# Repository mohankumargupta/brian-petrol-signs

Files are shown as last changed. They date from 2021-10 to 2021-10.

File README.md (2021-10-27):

# Big LED Matrix from Petrol Pump Signage

#### Info

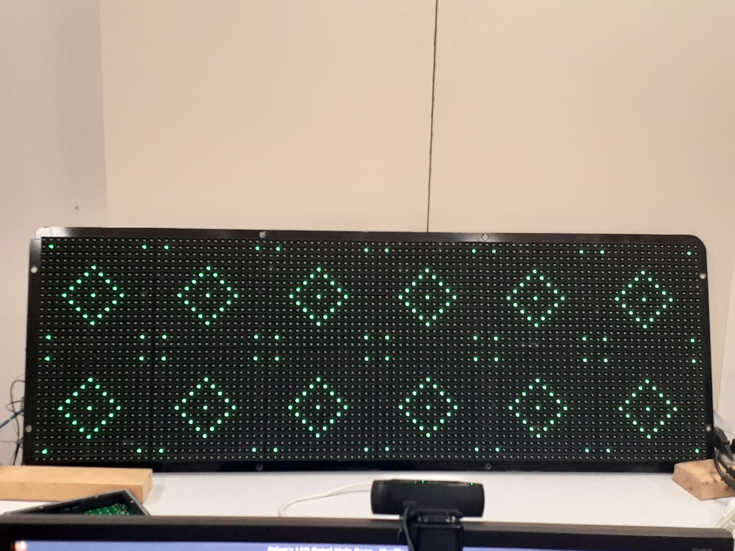
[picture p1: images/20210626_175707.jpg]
LED Panel Demo


Not the usual HUB08/HUB12/HUB40/HUB75 style setup. Inner workings [here](https://github.com/microcontrollersig/brian-led-matrix-petrol-signs/blob/main/REVERSEENGINEER.md)

They usually come in 6 panels wide, 2 panels height (effectively becomes a 96x32 single-color LED matrix)

# PCB Controller for LED matrix

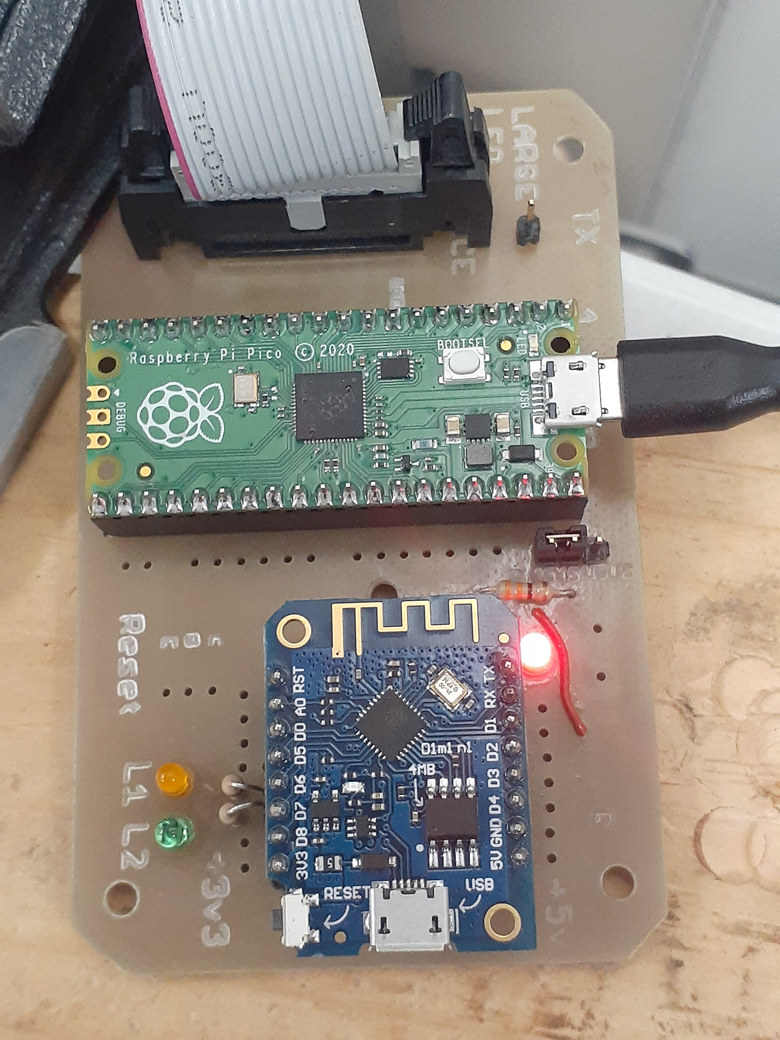
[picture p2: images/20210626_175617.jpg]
LED matrix controller


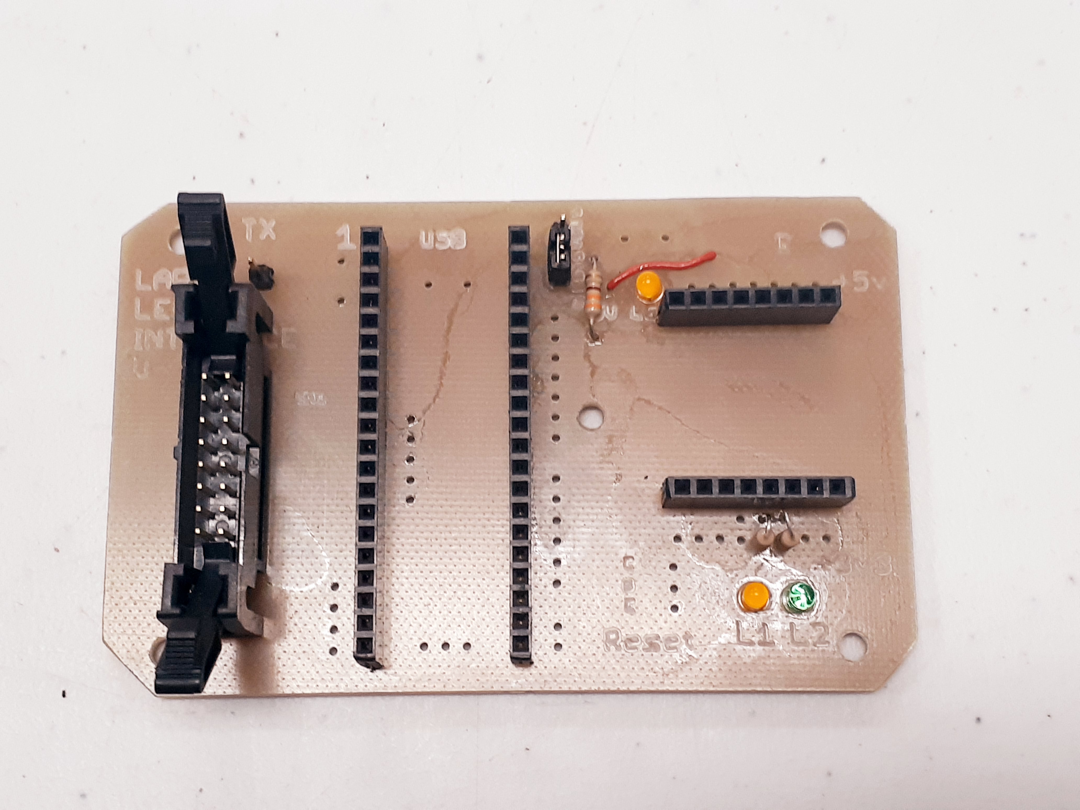
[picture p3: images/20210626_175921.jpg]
PCB controller


#### Bill of Materials

| Qty | |Code | Where to Buy | Required |
| --- |---|---| --- | --- |
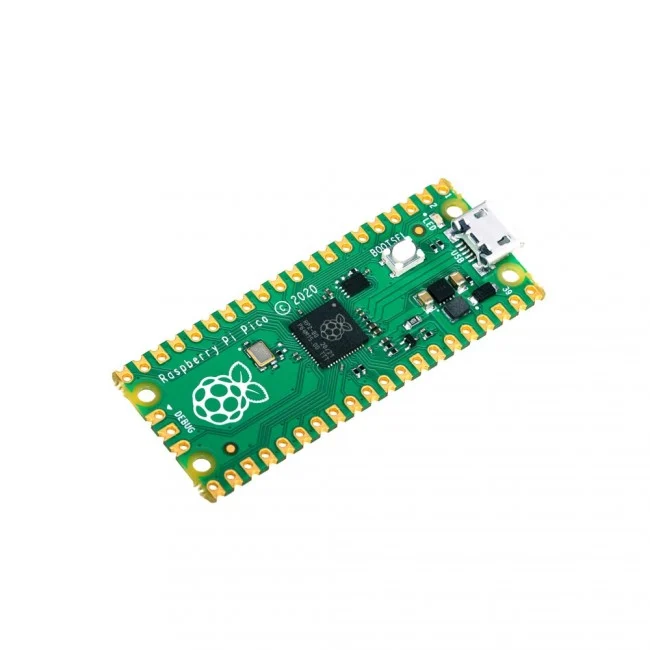
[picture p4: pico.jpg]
Pico
| 1 | |[Raspberry Pico](https://www.raspberrypi.org/documentation/rp2040/getting-started/) | [Pi Australia](https://raspberry.piaustralia.com.au/products/raspberry-pi-pico?variant=32587824070705)<br/>[Altronics](https://www.altronics.com.au/p/z6421-raspberry-pi-pico-microcontroller-board/)<br/>[Element 14](https://au.element14.com/raspberry-pi/raspberry-pi-pico/raspberry-pi-32bit-arm-cortex/dp/3643332)<br/>[Core Electronics](https://core-electronics.com.au/raspberry-pi-pico.html)| Y |
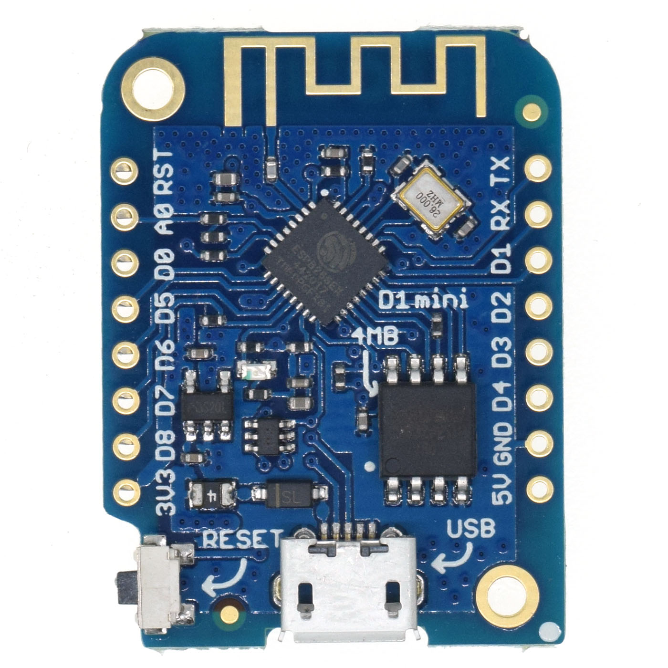
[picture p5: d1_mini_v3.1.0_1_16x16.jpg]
D1 mini
| 1 |  | [ESP8266 Wemos D1 mini](https://www.wemos.cc/en/latest/d1/d1_mini.html) | [Aliexpress - color: d1 mini](https://www.aliexpress.com/item/32651747570.html)  | Y |
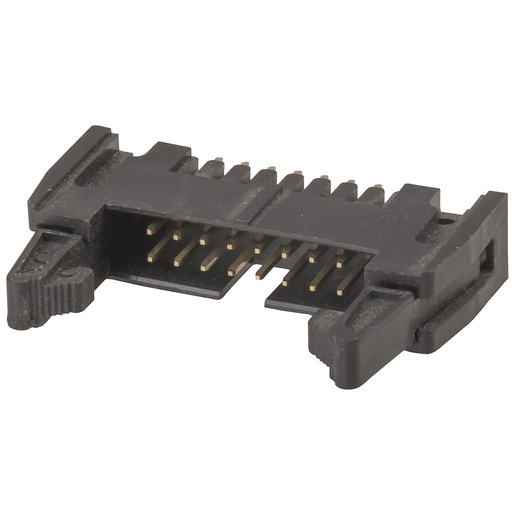
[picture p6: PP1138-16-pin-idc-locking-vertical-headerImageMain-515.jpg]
16 Pin IDC
| 1 |  | [16 Pin IDC Locking Vertical Header](https://www.jaycar.com.au/16-pin-idc-locking-vertical-header/p/PP1138) | 16-pin ribbon header| Y |
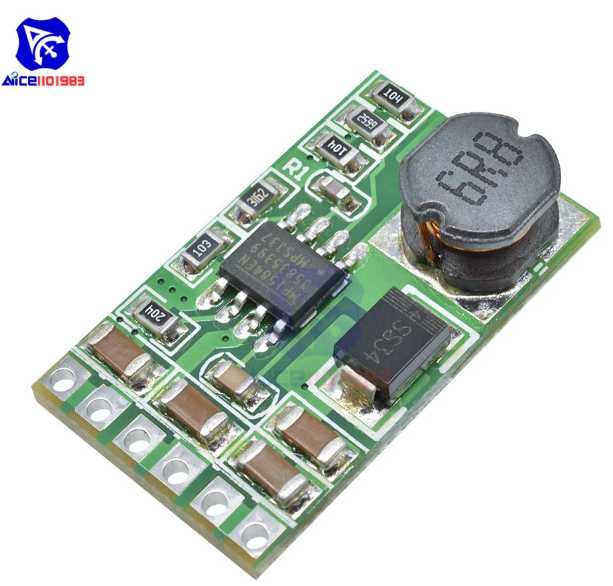
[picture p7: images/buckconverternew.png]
buck converter
| 1 |  | [3.5A buck converter - color: 5V](https://www.aliexpress.com/item/33036075561.html) | Buck converter | Y | 
| 1 | Terminal block | [Terminal block](https://www.altronics.com.au/p/p2041a-dinkle-3-way-5.08mm-pcb-mount-terminal-block/) | External power source | Y |
| 1 | Female header | [Female header](https://www.jaycar.com.au/40-pin-female-header-strip/p/HM3230) | Female header for Pico | Y |
| 1 | Right-angle connector | [Right-angle connector ](https://www.altronics.com.au/p/p5440-oupiin-40-way-90-degree-header-pin/) | Need for connecting buck converter | Y |
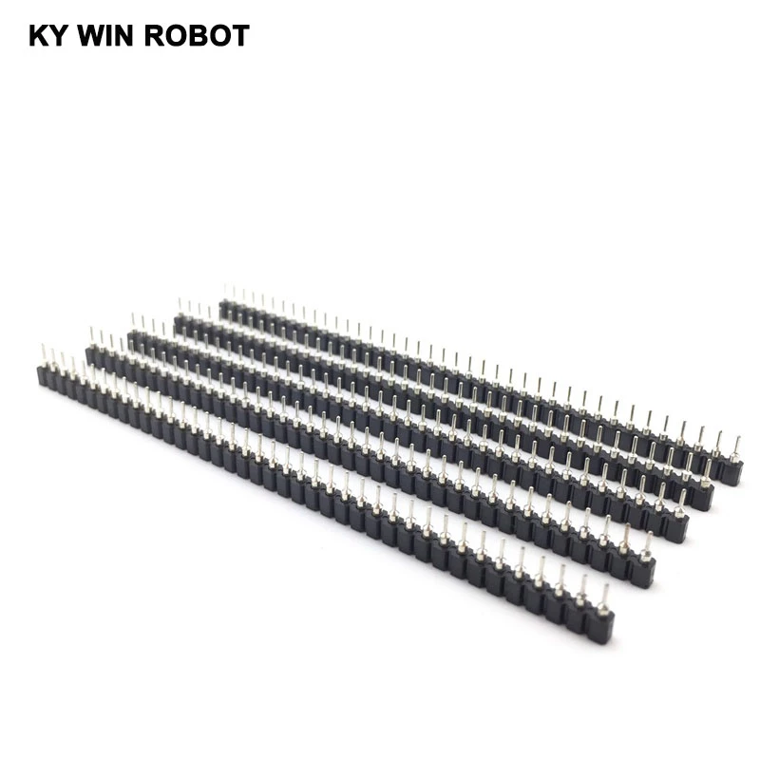
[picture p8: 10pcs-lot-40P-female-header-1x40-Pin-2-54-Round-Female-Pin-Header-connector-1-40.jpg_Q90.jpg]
Female Header
| 1 |  | [Round Female Pin Header connector - snapable](https://www.aliexpress.com/item/32848204130.html)  | Aliexpress | N |
| 1 | 2N2222A | [2N2222A NPN transistor](https://www.jaycar.com.au/2n2222a-npn-transistor/p/ZT2298) |  Pico software-controlled reset switch  | N |

#### EAGLE Schematic for PCB Board
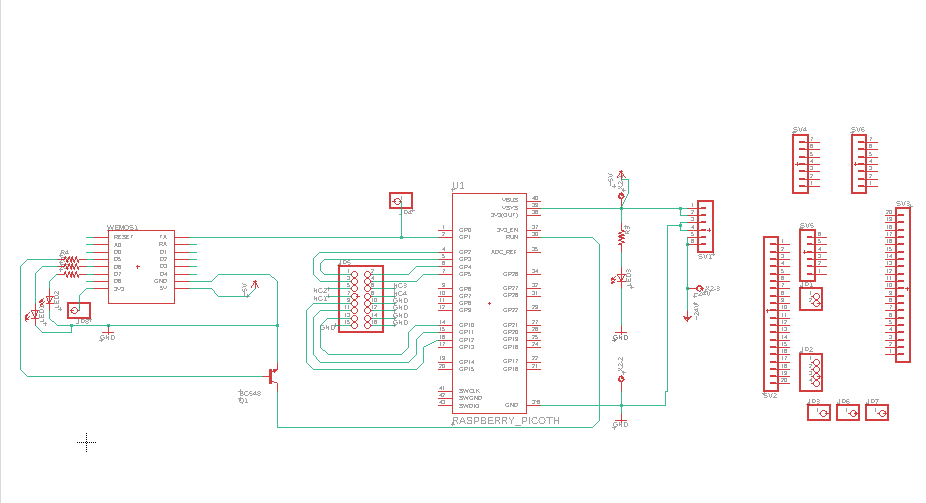
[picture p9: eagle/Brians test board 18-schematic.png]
schematic


#### EAGLE Board file for PCB Board

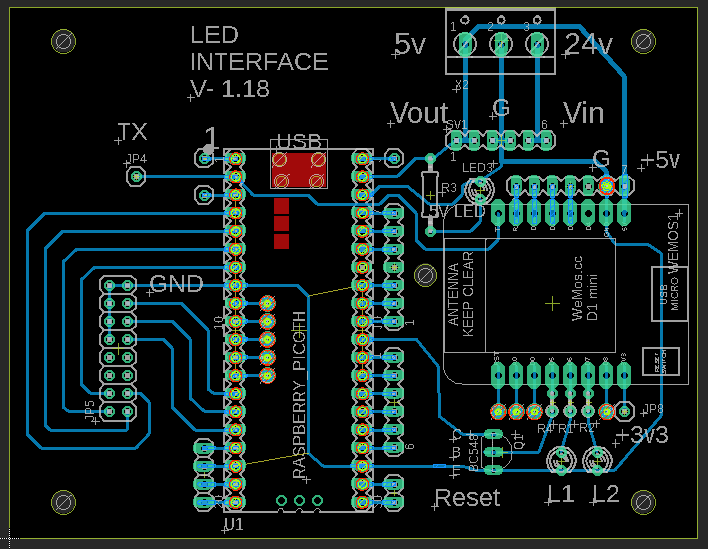
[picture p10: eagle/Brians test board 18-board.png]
board


### PCB Top Layer

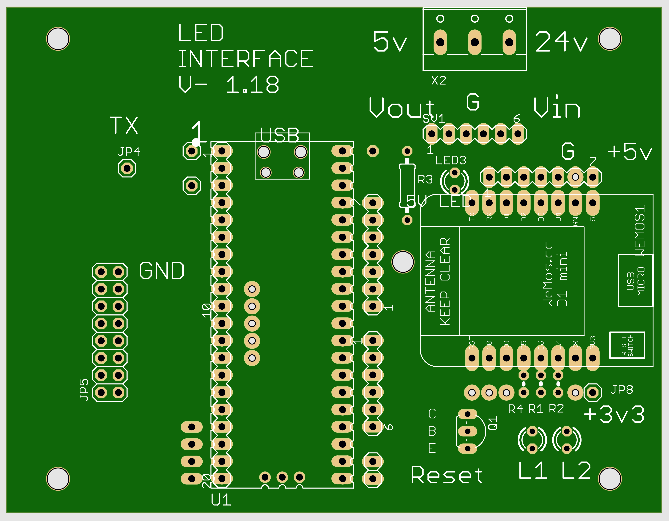
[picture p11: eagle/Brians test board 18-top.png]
PCB Top Layer


#### PCB Bottom Layer

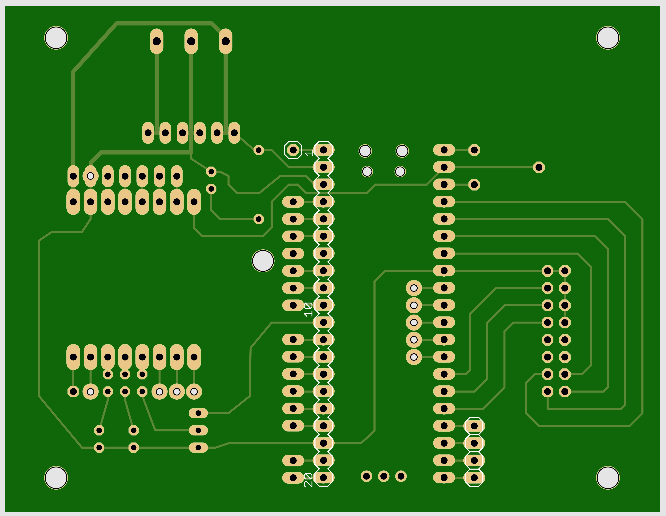
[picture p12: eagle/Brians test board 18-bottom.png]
PCB Bottom Layer


#### Raspberry Pi Pico

pinout

#### ESP8266 wemos d1 mini

pinout

# Software

## Uploading code to Raspberry Pico

The purpose of the Raspberry Pico:

* update LED matrix 
* receive commands from the D1 mini via serial(RX).

You can either upload code using the Arduino IDE or simply use the binary file with extension **uf2**

Procedure for either method [here](https://github.com/microcontrollersig/brian-led-matrix-petrol-signs/tree/main/code/pico).

## Uploading code to D1 mini

You can either upload code using the Arduino IDE or using an ESP8266 flashing tool such as ESPHome Flasher and the binary file that ends with extension **bin**

Procedure for either method [here](https://github.com/microcontrollersig/brian-led-matrix-petrol-signs/tree/main/code/d1mini)

The purpose of the D1 mini:

* Present user with web interface for controlling LED matrix. 
* Send commands for the Pico to execute on the LED matrix via Serial(TX).

# References

* [How LED matrix was reverse engineered](https://github.com/microcontrollersig/brian-led-matrix-petrol-signs/blob/main/REVERSEENGINEER.md)

* [Eagle files](https://github.com/microcontrollersig/brian-led-matrix-petrol-signs/tree/main/eagle)

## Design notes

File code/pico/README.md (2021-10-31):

# Uploading code to Raspberry Pico

#### Method 1 Using the UF2 binary file (easiest)

1. Download the UF2 binary file from [here](https://github.com/mohankumargupta/brian-petrol-signs/releases/latest/pico.uf2)

2. Press and hold the **BOOTSEL** button on the Raspberry Pico while connecting the USB cable to the PC. Once USB is connected to PC, release button.

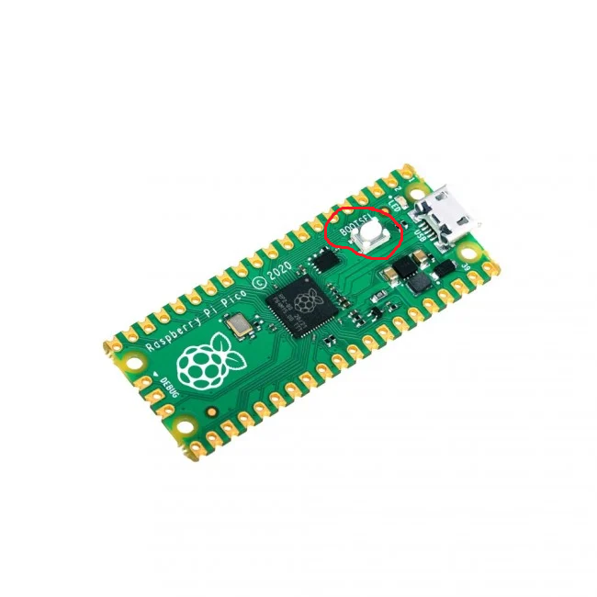
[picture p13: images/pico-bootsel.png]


3. If successful, the Pico will show up as USB drive in File Explorer as **RPI-RP2**.

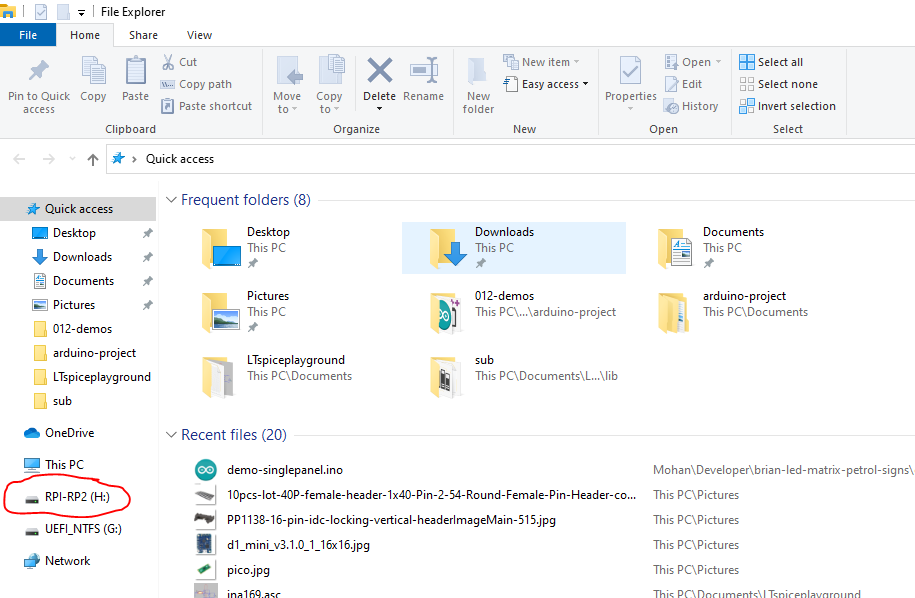
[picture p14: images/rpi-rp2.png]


4. Copy the UF2 binary file to the USB drive. After copying, the USB drive will disappear. The program has been
   successfully uploaded!

#### Method 2 Using the Arduino IDE (harder)
You can pick out the important steps from [here](https://github.com/microcontrollersig/brian-led-matrix-petrol-signs/blob/main/code/pico/BUILDING.md)

# Extras

#### Fonts

[1001freefonts](https://www.1001freefonts.com/lcd-fonts.php)

# Troubleshooting a Raspberry Pico

### Unbricking a Pico

If you need to hit the panic button, download this factory reset uf2 from [here](https://www.raspberrypi.org/documentation/pico/getting-started/static/6f6f31460c258138bd33cc96ddd76b91/flash_nuke.uf2)

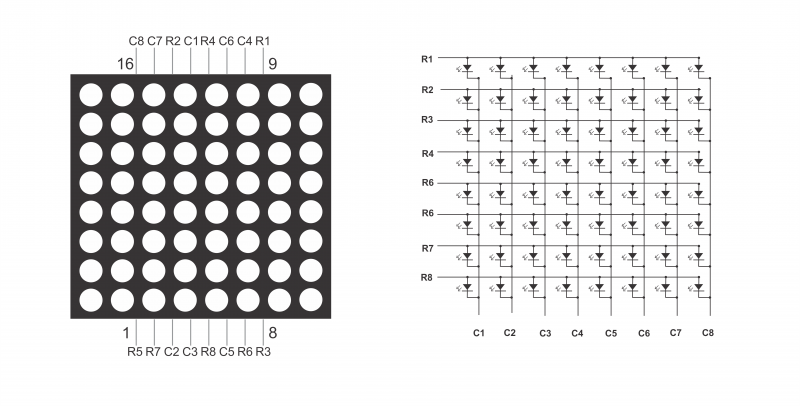
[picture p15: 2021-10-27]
8X8-Matrix-Pinout-800x406.png

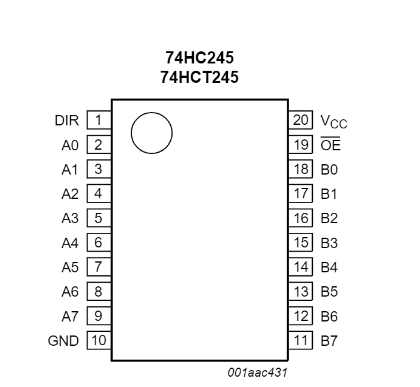
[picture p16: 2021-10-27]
74HC245-pinout.png

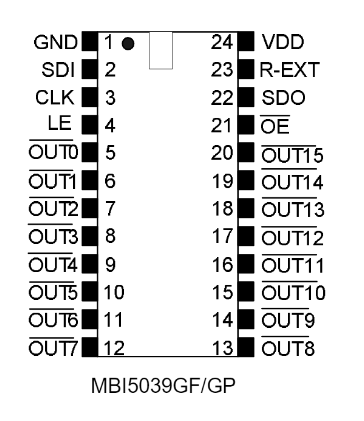
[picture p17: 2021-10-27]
mbi5039-pinout.png

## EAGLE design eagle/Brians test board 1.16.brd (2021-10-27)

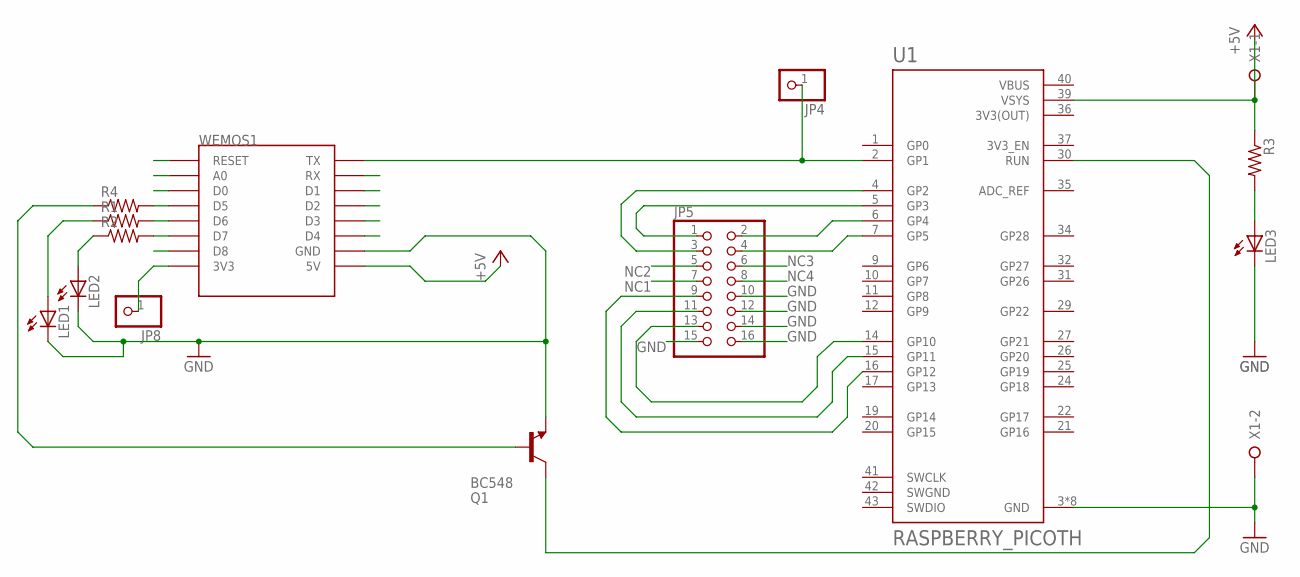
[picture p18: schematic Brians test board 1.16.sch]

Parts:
JP4, JP8: PINHD-1X1; 1X01
JP5: PINHD-2X8; 2X08
LED1, LED2, LED3: LED3MM
Q1: BC548; TO92-EBC
R1, R2, R4: R-US_0204/2V; 0204V
R3: R-US_0207/10; 0207/10
U1: RASPBERRY_PICOTH; PICO-PKG-TH
WEMOS1: WEMOS-D1-MINI
X1: W237-02P; W237-132

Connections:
3V3(OUT): U1.36 (3V3(OUT))
+5V: R3.1, U1.39 (VSYS), WEMOS1.5V, X1.1
A0: WEMOS1.A0
D0: WEMOS1.D0
D1: WEMOS1.D1
D2: WEMOS1.D2
D3: WEMOS1.D3
D4: WEMOS1.D4
D8: WEMOS1.D8
GND: JP5.10, JP5.12, JP5.14, JP5.15, JP5.16, LED1.K (C), LED2.K (C), LED3.K (C), Q1.E, U1.3 (GND), U1.8 (GND), U1.13 (GND), U1.18 (GND), U1.23 (GND), U1.28 (GND), U1.33 (GND), U1.38 (GND), WEMOS1.GND, X1.2
unnamed: JP5.1, U1.5 (GP3)
unnamed: JP8.1, WEMOS1.3V3
unnamed: Q1.C, U1.30 (RUN)
unnamed: JP4.1, U1.2 (GP1), WEMOS1.TX
unnamed: JP5.3, U1.4 (GP2)
unnamed: R2.2, WEMOS1.D7
unnamed: JP5.13, U1.14 (GP10)
unnamed: JP5.11, U1.15 (GP11)
unnamed: JP5.9, U1.16 (GP12)
unnamed: JP5.2, U1.6 (GP4)
unnamed: JP5.4, U1.7 (GP5)
unnamed: R1.2, WEMOS1.D6
unnamed: LED2.A, R2.1
unnamed: LED1.A, R1.1
unnamed: LED3.A, R3.2
unnamed: R4.2, WEMOS1.D5
unnamed: Q1.B, R4.1
NC1: JP5.7
NC2: JP5.5
NC3: JP5.6
NC4: JP5.8
RST: WEMOS1.RESET
RX: WEMOS1.RX
SWGND: U1.42 (SWGND)
VBUS: U1.40 (VBUS)

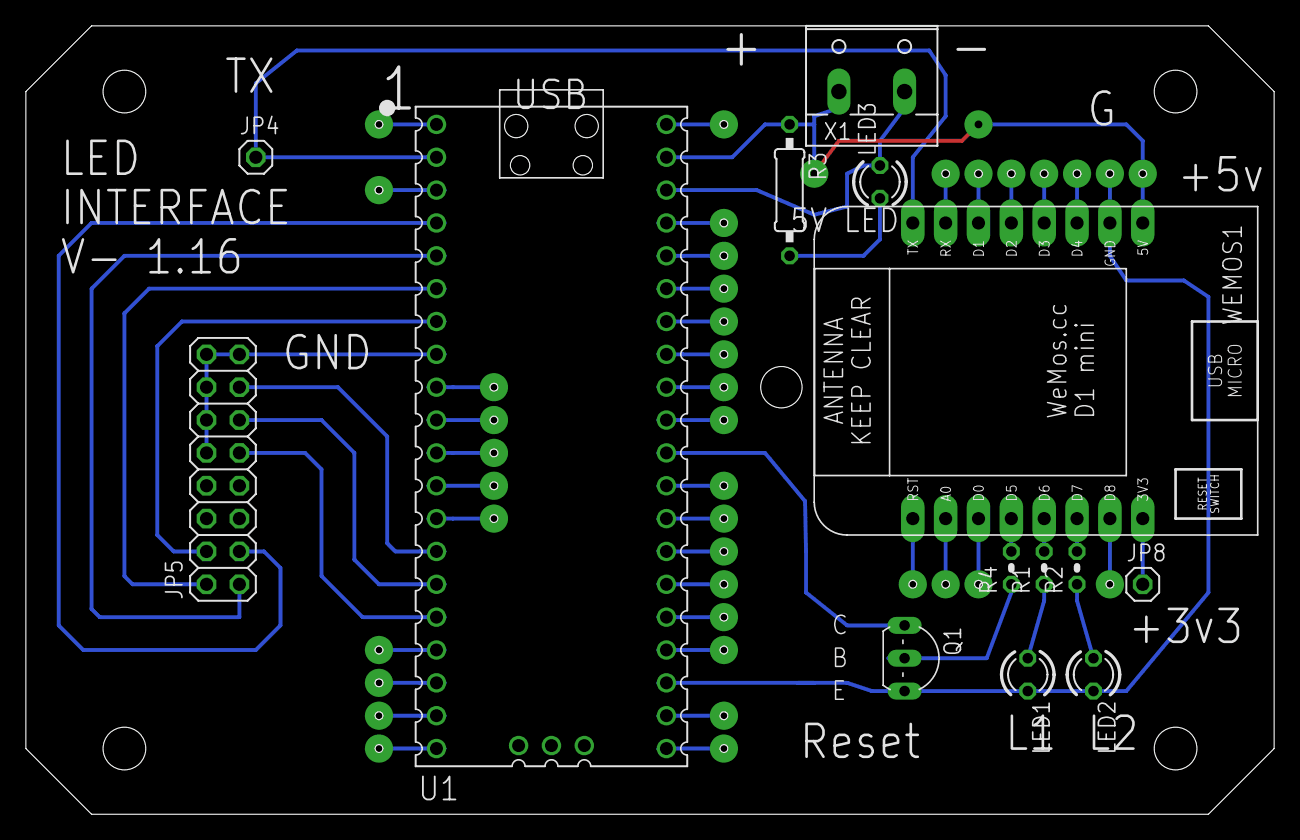
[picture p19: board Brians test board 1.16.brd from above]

Board: 2 copper layers, 96.5 x 61.0 mm, 14 parts (0 on the bottom side), 19 nets.

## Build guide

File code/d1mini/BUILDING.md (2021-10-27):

# Building

1. Install Arduino IDE
2. Install ESP8266 Arduino core from git , NOT the usual Boards Manager way. [Instructions here](https://arduino-esp8266.readthedocs.io/en/latest/installing.html#using-git-version)
3. Install LittleFS arduino plugin [here](https://github.com/earlephilhower/arduino-esp8266littlefs-plugin) 
4. Upload sketch as normal.
5. Tools->ESP8266 LittleFS Data Upload

# ESP8266 Flash Layout

ESP8266 Flash Layout

### Creating BIN file

```shell
esptool --port COM9 --baud 921600 read_flash 0x00000 0x400000 d1mini.bin
```

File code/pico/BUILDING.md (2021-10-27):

# Building the UF2 file

Use the latest Arduino IDE (1.8.15 at the time of writing).

1. Install the Arduino Mbed board for RP2040 
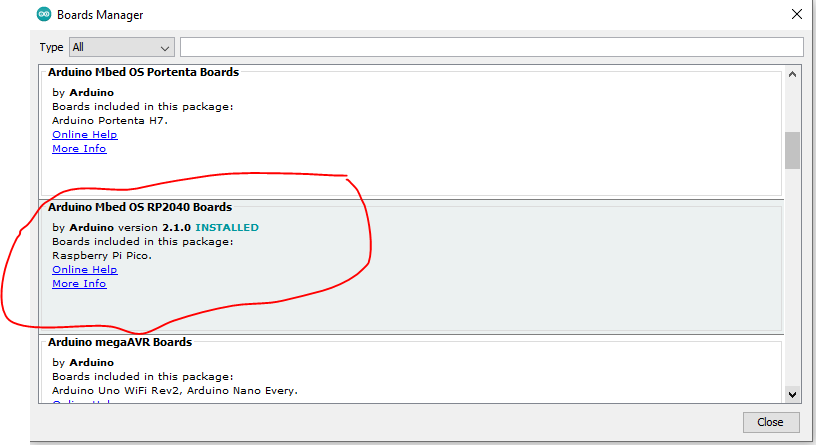
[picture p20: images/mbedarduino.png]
Mbed Arduino
   
2. In Arduino preferences, enable **Show verbose output during** for both compilation and upload.
3. Build. The last line will indicate the location of the **elf** binary file. You will need access to this file.
4. Install elf2uf2 tool from the Pico SDK.

   On Windows, install msys2, then:
   ```shell
   pacman -Syuu
   pacman -S base-devel gcc make cmake git
   git clone  https://github.com/raspberrypi/pico-sdk
   cd pico-sdk/tools/elf2uf2
   mkdir build
   cd build
   cmake ..
   make
   ./elf2uf2 -v <name_of_binary.elf> <name_of_binary.uf2>
   ```
5. You can upload to Pico as normal in Arduino IDE if you don't need the UF2 file.

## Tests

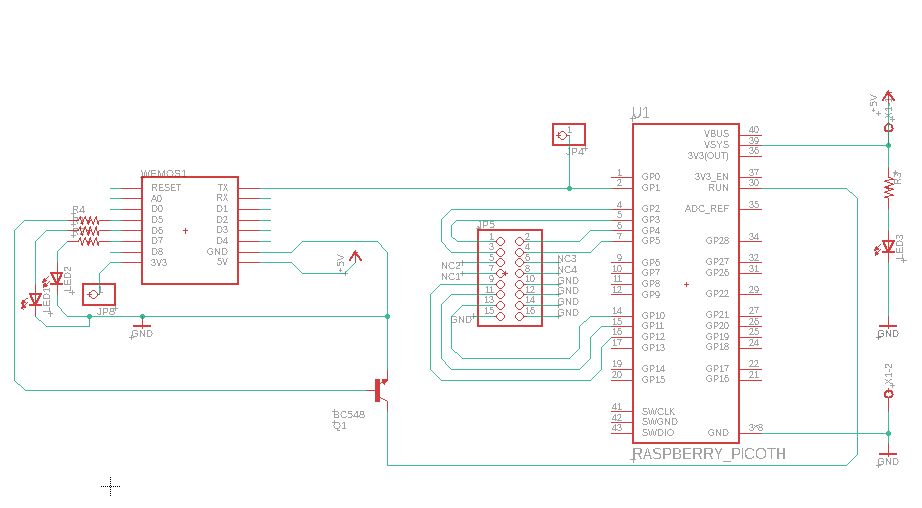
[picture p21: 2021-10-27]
eagle/Brians test board 16-schematic.png

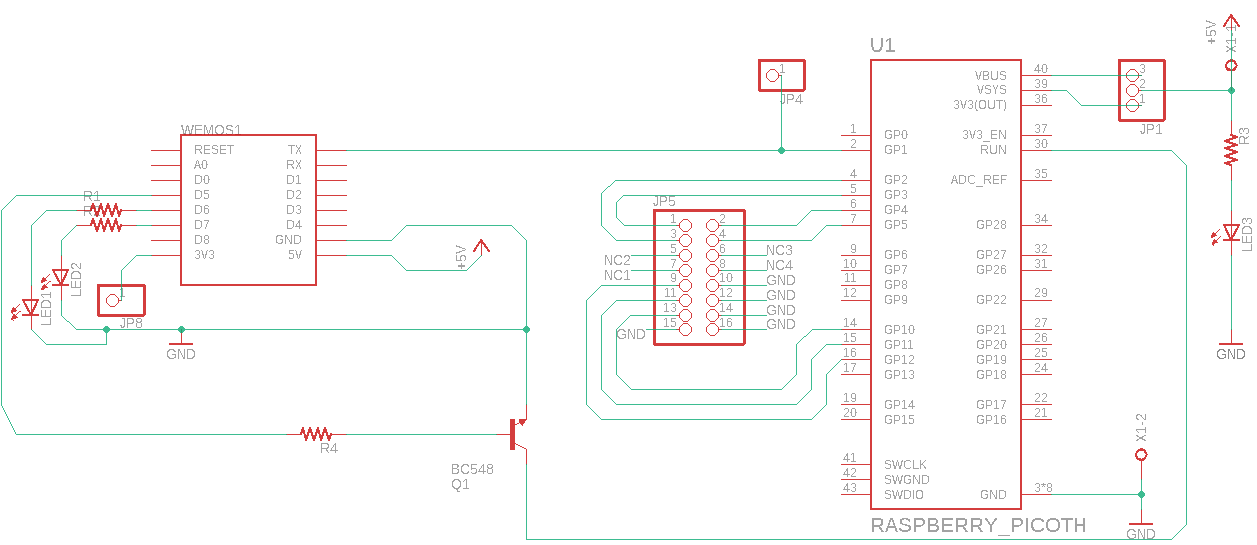
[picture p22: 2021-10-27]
eagle/Brians test board 1.12a-schematic-mohan.png

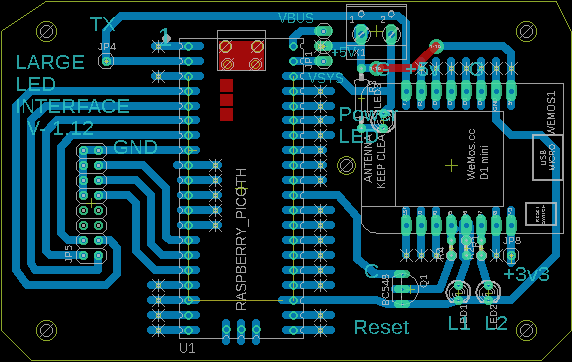
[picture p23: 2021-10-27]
eagle/Brians test board 1.12a-board-mohan.png

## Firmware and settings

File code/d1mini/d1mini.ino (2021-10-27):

#include <DNSServer.h>
#ifdef ESP32
#include <WiFi.h>
#include <AsyncTCP.h>
#elif defined(ESP8266)
#include <ESP8266WiFi.h>
#include <ESPAsyncTCP.h>
//#include <ESP8266mDNS.h>
#endif
#include "ESPAsyncWebServer.h"
#include <LittleFS.h>
#include <Ticker.h>
#include <AsyncJson.h>
#include <ArduinoJson.h>
#define WIFI_TIMEOUT 10000


//#define DEBUG 0
#define DEBUG 1 

#define debug_print(val) do { if (DEBUG) Serial.print(val); } while(0)
#define debug_println(val) do { if (DEBUG) Serial.println(val); } while(0)
#define update_ledmatrix_ipaddress(val) do { Serial.print("{I`"); Serial.print(val);Serial.println("}"); } while(0)
#define update_ledmatrix_command(val) do { Serial.print("{"); Serial.print(val);Serial.println("}"); } while(0)
#define update_ledmatrix_command_with_arg(command, arg1) do {Serial.print("{"); Serial.print(command);Serial.print("`");Serial.print(arg1);Serial.println("}"); } while(0)


DNSServer dnsServer;
AsyncWebServer server(80);
bool restartESP = false;
Ticker ticker;

void restartESPCallback() 
{
  ESP.restart();
}

class CaptiveRequestHandler : public AsyncWebHandler {
public:
  CaptiveRequestHandler() {

   server.serveStatic("/css/", LittleFS, "/css/");
   server.serveStatic("/js/", LittleFS, "/js/");
   server.serveStatic("/fonts/", LittleFS, "/fonts/");
    
    server.on("/wificredentials", HTTP_POST, [](AsyncWebServerRequest *request){
      int params = request->params();
      AsyncWebParameter *ssid = request->getParam(0);
      AsyncWebParameter *wifipassword = request->getParam(1);
            
      debug_print("Number of params: ");
      debug_println(params);
      debug_print("SSID: ");
      debug_println(ssid->value().c_str());
      debug_print("Wifi password: ");
      debug_println(wifipassword->value().c_str());
            
      File file = LittleFS.open("wifi.cfg", "w");      
      file.print(ssid->value().c_str());  
      file.print(',');
      file.print(wifipassword->value().c_str());       
      file.close();
      
      AsyncWebServerResponse* response = request->beginResponse(LittleFS, "/captiverestart.htm", "text/html");
      request->send(response);
      ticker.attach(5, restartESPCallback);
    });

   server.on("/main", HTTP_GET, [](AsyncWebServerRequest *request){
         request->send(LittleFS,  "/index.htm", "text/html");
   });

   server.on("/command", HTTP_POST, [](AsyncWebServerRequest *request){
         int params = request->params();
         AsyncWebParameter *c = request->getParam(0);
         char command[100];
         strcpy(command,  c->value().c_str());
                
         debug_print("{");
         debug_print(*command);
 
         for (int i=1; i<params; i++) {
           debug_print("`");
           
           AsyncWebParameter *d = request->getParam(i);
           debug_print(d->value().c_str());
         }
     
         debug_print("}");
         debug_println();
    

         request->send(204);        
   });
      
  }
  virtual ~CaptiveRequestHandler() {}

  bool canHandle(AsyncWebServerRequest *request){
    //request->addInterestingHeader("ANY");
    return true;
  }

  void handleRequest(AsyncWebServerRequest *request) {
    //AsyncResponseStream *response = request->beginResponseStream("text/html");
    request->send(LittleFS,  "/captiveportal.htm", "text/html");
    // Captive portal is at: 192.168.4.1
    //request->send(response);
  }
};



void startCaptiveWebServer()
{
  WiFi.softAP("brianLEDPanels");
  dnsServer.start(53, "*", WiFi.softAPIP());
  server.addHandler(new CaptiveRequestHandler()).setFilter(ON_AP_FILTER);//only when requested from AP
  server.begin(); 
  update_ledmatrix_ipaddress("192.168.4.1"); 
}

void startWebServer() 
{
   server.serveStatic("/css/", LittleFS, "/css/");
   server.serveStatic("/js/", LittleFS, "/js/");
   server.serveStatic("/fonts/", LittleFS, "/fonts/");
  
   server.on("/command", HTTP_POST, [](AsyncWebServerRequest *request){
         int params = request->params();
         AsyncWebParameter *c = request->getParam(0);
         char command[100];
         strcpy(command,  c->value().c_str());
                
         debug_print("{");
         debug_print(*command);
 
         for (int i=1; i<params; i++) {
           debug_print("`");
           
           AsyncWebParameter *d = request->getParam(i);
           debug_print(d->value().c_str());
         }
     
         debug_print("}");
         debug_println();
    

         request->send(204);        
   });

   AsyncCallbackJsonWebHandler* handler = new AsyncCallbackJsonWebHandler("/homeassistant", [](AsyncWebServerRequest *request, JsonVariant &json) {
     { //scope JsonDocument so it releases its buffer
      JsonObject jsonObj = json.as<JsonObject>();  
      const char *command = jsonObj["command"];
      int argumentCount = jsonObj["argumentCount"];
      
      Serial.print("{");
      Serial.print(command);
      for (int i=0; i < argumentCount; i++) {
        const char *argument = jsonObj["arguments"][i];
        Serial.print("`");
        Serial.print(argument);
      }
      Serial.print("}");
      Serial.println();
      request->send(200);
     } 
   });
   server.addHandler(handler);
     
AsyncCallbackJsonWebHandler* settingsSubmitHandler = new AsyncCallbackJsonWebHandler("/settingsSubmit", [](AsyncWebServerRequest *request, JsonVariant &json) {
  
  
  if (request->method() == HTTP_POST) {
       DynamicJsonDocument doc(2048);
       doc["brightness"] = json["brightness"];
       doc["bootcommand"] = json["bootcommand"];
       doc["bootcommanddescription"] = json["bootcommanddescription"];
      
       File settingsFile = LittleFS.open("/settings.json", "w");
       serializeJson(json, settingsFile);
       request->send(200);  
       settingsFile.close();     
  }

  
  
});
server.addHandler(settingsSubmitHandler);

   server.on("/settings", HTTP_GET, [](AsyncWebServerRequest *request) {
     File settingsFile = LittleFS.open("/settings.json", "r");
     request->send(200, "application/json", settingsFile.readString());
     settingsFile.close();
   });

   /*
   server.on("/settings", HTTP_POST, [](AsyncWebServerRequest *request) { 
      request->send(200);
   }, NULL, [](AsyncWebServerRequest *request, uint8_t *data, size_t len, size_t index, size_t total) {        
        if (index == 0) {
          request->_tempObject = new char[len + 1];
          char* tempObject = (char *)request->_tempObject;
          
          for (int i=0; i<len; i++) {
            tempObject[i] = (char)data[i];
          }

          tempObject[len] = '\0';
          
          //Serial.println(tempObject);
          DynamicJsonDocument doc(1024);
          deserializeJson(doc, tempObject);
          File settingsFile = LittleFS.open("/settings.json", "w");
          serializeJson(doc, settingsFile);
          settingsFile.close();
          
        }

        else {
          Serial.println("It gets here");
        }
  });
 */
   /*
   AsyncCallbackJsonWebHandler* settingsHandler = new AsyncCallbackJsonWebHandler("/settings", [](AsyncWebServerRequest *request, JsonVariant &json) {
     debug_println("We got here!");
     if (request->method() == HTTP_GET) {
       request->send(LittleFS,  "/settings.htm", "text/html"); 
     }

     else if (request->method() == HTTP_POST) {
       File settingsFile = LittleFS.open("/settings.json", "w");
       serializeJson(json, settingsFile);
       settingsFile.close();
       request->send(200);     
     }
   });
   server.setMethod(HTTP_ANY);
   server.addHandler(settingsHandler);
   */

   server.on("/savedsettings", HTTP_GET, [](AsyncWebServerRequest *request) {
     File settingsFile = LittleFS.open("/settings.json", "r");
     request->send(settingsFile, "application/json", settingsFile.size());
     /*settingsFile.close();*/
     /*
  
     std::unique_ptr<char[]> buf(new char[settingsFileSize]);
     settingsFile.readBytes(buf.get(), settingsFileSize);
     settingsFile.close();
     request->send(200, "application/json", buf.get());
     */

     /*
     StaticJsonDocument<512> doc;
     deserializeJson(doc, settingsFile);
     settingsFile.close();
     */
     /*JsonObject root = doc.as<JsonObject>();*/
     
     /*
     AsyncJsonResponse * response = new AsyncJsonResponse();
     response->addHeader("Server","ESP Async Web Server");
     JsonVariant& jsonObj = response->getRoot();

     jsonObj["brightness"] = root["brightness"];
     jsonObj["bootcommand"] = root["bootcommand"];

     response->setLength();
     request->send(response);
     */
   });
  
   server.on("/", HTTP_GET, [](AsyncWebServerRequest *request){
     request->send(LittleFS,  "/index.htm", "text/html");
   });



   
   server.begin();

    debug_println("Web server started");
  

}

void parseWifiCfg(char *ssid, char *password)
{
  File f = LittleFS.open("wifi.cfg", "r");
  
  if (f.available() > 0) {
     size_t bytesRead = f.readBytesUntil(',', ssid, 100);
     ssid[bytesRead] = '\0';
     //debug_print("ssid byte count:");
     //debug_println(bytesRead);
  }
  
  int i;
  for (i=0; f.available() > 0 ; i++) {
    password[i] = f.read();
  }
  password[i] = '\0';
  f.close();
}

void send_bootcommand(const String& ipaddress) {
  File settingsFile = LittleFS.open("/settings.json", "r");
  DynamicJsonDocument doc(1024);
  deserializeJson(doc, settingsFile);
  JsonObject root = doc.as<JsonObject>();
  String bootcommand = root["bootcommand"];
  String brightness = root["brightness"];
  if (bootcommand == "") {
    update_ledmatrix_ipaddress(ipaddress);
  }

  else {
    update_ledmatrix_command(bootcommand);
  }
  update_ledmatrix_command_with_arg("B", brightness);
  settingsFile.close();
}

void wificonfig() 
{
  Dir dir = LittleFS.openDir ("");
  while (dir.next()) {
    if (dir.fileName() == "wifi.cfg"){
      if (dir.fileSize() == 0) {
        debug_println("Starting captive portal...");
        startCaptiveWebServer();        
      }

      else {
        char ssid[100], password[100];
        debug_println("Attempting to parse wifi.cfg ...");
        parseWifiCfg(ssid, password);
        debug_print("SSID retrieved from wifi.cfg:");
        debug_println(ssid);
        debug_print("password retrieved from wifi.cfg:");
        debug_println(password);
        debug_println("Attempting to connect to wifi...");
        WiFi.begin(ssid,password);
        WiFi.waitForConnectResult(WIFI_TIMEOUT);
        if (WiFi.status() == WL_CONNECTED) {
          debug_println("Successfully connected to wifi.");
          debug_print("IP Address: ");
          debug_println(WiFi.localIP());
          send_bootcommand(WiFi.localIP().toString());
          //update_ledmatrix_text(WiFi.localIP().toString());
          startWebServer();
          /*
          if (!MDNS.begin("brian")) {
            debug_println("Error setting up MDNS responder!");
            while(1) {
              delay(1000);
            }
           }
          debug_println("mDNS responder started");
          // Add service to MDNS-SD
          MDNS.addService("http", "tcp", 80);
          */
        }

        else {
          debug_println("Couldn't connect to wifi. Starting Soft AP.");
          File file = LittleFS.open("wifi.cfg", "w");  
          file.close();
          startCaptiveWebServer();
        } 
               
      }
    }
  }
}


void setup(){
  Serial.begin(115200);
  delay(5000);
  if (DEBUG)
    Serial.println("Debugging ON."); 
  else
    Serial.println("Debugging OFF.");
  debug_println("begin wifi route...");
  // Initialize SPIFFS
  if(!LittleFS.begin()){
    delay(5000);
    debug_println("An Error has occurred while mounting LittleFS. Did you forget to upload fs using ESP8266 LittleFS Data upload?");
    return;
  }

  if (!LittleFS.exists("wifi.cfg"))
  {
    delay(5000);
    debug_println("wifi.cfg does not exist. Did you forget to upload fs using ESP8266 LittleFS Data upload?"); 
    return;
  }

  wificonfig();
}

void loop(){
  if (restartESP) {
    restartESP = false;
    ESP.restart();  
  }
  dnsServer.processNextRequest();
}

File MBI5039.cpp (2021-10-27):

#include "MBI5039.h"

#if defined(ESP8266)
#define MAX_PWM_VALUE 1023
#else
#define MAX_PWM_VALUE 255
#endif



void MBI5039::setBrightness(float b)
{
  brightness = (int) ((1.0 - b) * MAX_PWM_VALUE);
}

void MBI5039::disable()
{
  digitalWrite(noe_pin, HIGH);
}

void MBI5039::enable()
{
  analogWrite(noe_pin, brightness);
}

void MBI5039::latch()
{
  delayMicroseconds(250);
  digitalWrite(latch_pin, HIGH);
  delayMicroseconds(250);
  digitalWrite(latch_pin, LOW);
  delayMicroseconds(250);
}

void MBI5039::sendDataMSB(uint8_t *data1, uint8_t *data2, uint8_t *data3, uint8_t *data4)
{
   sendData(data1, data2, data3, data4, true);    
}

void MBI5039::sendDataLSB(uint8_t *data1, uint8_t *data2, uint8_t *data3, uint8_t *data4)
{
   sendData(data1, data2, data3, data4, false);
}

void MBI5039::sendData(uint8_t *data1, uint8_t *data2, uint8_t *data3, uint8_t *data4, bool bitOrder) 
{
  uint8_t mask;
  if (bitOrder) 
    mask = 0x80;
  else
    mask = 1;

  //Serial.println("What...");

  for (int i=0; i<8; i++)
  {
    
    sendOneBit(*data1, *data2, *data3, *data4, mask);

    if (bitOrder)
      mask = mask >> 1;
    else
      mask = mask << 1;

    digitalWrite(clock_pin, LOW);
    delay(1);
    digitalWrite(clock_pin, HIGH);
    delay(1);
    digitalWrite(clock_pin, LOW);
  }

  digitalWrite(data1_pin, LOW);
  digitalWrite(data2_pin, LOW);
  digitalWrite(data3_pin, LOW);
  digitalWrite(data4_pin, LOW);
}

void MBI5039::sendData(uint16_t data1, uint16_t data2, uint16_t data3, uint16_t data4, bool bitOrder) 
{

}

void MBI5039::sendOneBit(uint8_t data1, uint8_t data2, uint8_t data3, uint8_t data4, uint8_t mask)
{
  digitalWrite(data1_pin, (data1 & mask) ? HIGH:LOW);
  digitalWrite(data2_pin, (data2 & mask) ? HIGH:LOW);
  digitalWrite(data3_pin, (data3 & mask) ? HIGH:LOW);
  digitalWrite(data4_pin, (data4 & mask) ? HIGH:LOW);  
}

void MBI5039::sendOneBit(uint16_t data1, uint16_t data2, uint16_t data3, uint16_t data4, uint16_t mask)
{
  digitalWrite(data1_pin, (data1 & mask) ? HIGH:LOW);
  digitalWrite(data2_pin, (data2 & mask) ? HIGH:LOW);
  digitalWrite(data3_pin, (data3 & mask) ? HIGH:LOW);
  digitalWrite(data4_pin, (data4 & mask) ? HIGH:LOW);
}

/*
void MBI5039::myAnalogWrite(pin_size_t pin, int val) 
{
    mbed::PwmOut* pwm = new mbed::PwmOut(digitalPinToPinName(pin));
    //pwm->period_ms(2); //500Hz
    pwm->period_us(10); //100kHz
    float percent = val/255.0;
    pwm->write(percent);
}
*/
